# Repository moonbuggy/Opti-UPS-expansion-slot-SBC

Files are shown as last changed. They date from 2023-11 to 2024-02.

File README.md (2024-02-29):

# Opti-UPS Expansion Slot Single Board Computer
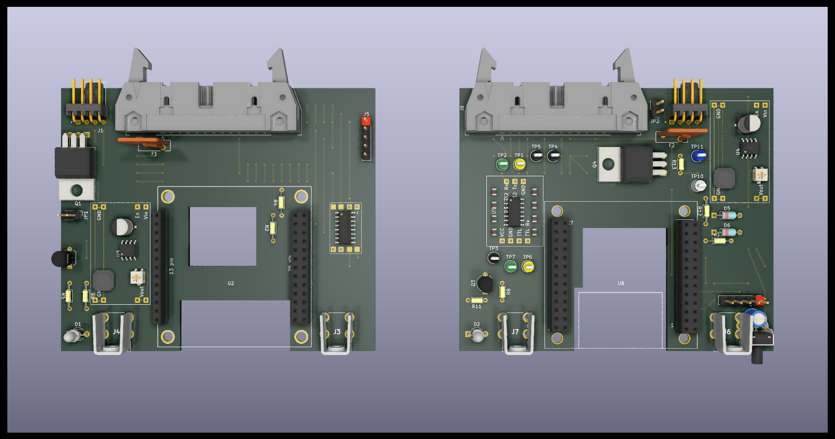
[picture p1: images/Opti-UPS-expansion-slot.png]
3D-render


KiCad files for circuits built on prototyping board that will fit in a UPS
expansion slot, to add an ethernet interface for network UPS management.

*   [Rationale](#rationale)
*   [Single Board Computers](#single-board-computers)
*   [Expansion Boards](#expansion-boards)
    +   [Assembled](#assembled)
    +   [Schematics](#schematics)
    +   [Layouts](#layouts)
    +   [Components](#components)
        -   [Pre-built Modules](#pre-built-modules)
        -   [Mounting](#mounting)
    +   [Status LED](#status-led)
    +   [I²C Header](#i-c-header)
        -   [Real-time Clock](#real-time-clock)
    +   [Fan Connector](#fan-connector)
    +   [Power Cycling](#power-cycling)
*   [Opti-UPS PS1440RM](#opti-ups-ps1440rm)
    +   [Expansion Slot](#expansion-slot)
    +   [Pinouts](#pinouts)
*   [Software](#software)
    +   [NUT](#nut)
        -   [Minimal configuration](#minimal-configuration)
    +   [chrony](#chrony)
    +   [Windows 2000 in Docker](#windows-2000-in-docker)
        -   [/etc/docker/daemon.json](#-etc-docker-daemonjson)
        -   [Dockerfile](#dockerfile)
        -   [docker-compose.yml](#docker-composeyml)
*   [Links](#links)
    +   [Datasheets](#datasheets)

These are designed with an Opti-UPS PS1440RM in mind, but should work in other
UPS expansion slots after adjusting for the pinout of the expansion slot
connection.

There's two different boards, for two different SBCs: an
[Orange Pi Zero](http://www.orangepi.org/orangepiwiki/index.php/Orange_Pi_Zero)
and a [Rock Pi S](https://wiki.radxa.com/RockpiS). There's more information here
about the Rock Pi S version because that's the one I ended up building.

## Rationale
My UPS is 20 years old but still works fine. Except, the official Opti-UPS
software for the UPS won't run in anything newer than Windows 2000 and I don't
want to run a VM on a real computer just to talk to the UPS.

Also, it's just nice to have ethernet coming right out of a UPS, rather than a
serial cable.

Proper expansion cards for the UPS aren't easy to find, due to its age, so
making something to fit seems sensible.

## Single Board Computers
The two SBCs offer different solutions to the problem. The Orange Pi Zero is
cheap and will happily run [Network UPS Tool (NUT)](https://networkupstools.org/).
The Rock Pi S is also relatively cheap, but _should_ be able to run [Windows 2000
in Docker](https://github.com/hectorm/docker-qemu-win2000), allowing the official
Opti-UPS software to run.

The Rock Pi S will want to draw more power than the Orange Pi Zero, and it's
overkill for just running NUT (which it will also happily do), but it is more
capable thus provides more flexibility.

These boards will work directly with other SBCs that have the same pin
arrangement (e.g. Orange Pi Zero 2 and Orange Pi Zero 3), although the spaces
in the boards to fit RJ-45/USB sockets and any CPU heatsinks may need to be
adjusted.

It's not too difficult to customise these boards for other SBCs with different
pin arrangements.

## Expansion Boards
Both boards are fundamentally the same. The main differences are the physical
layout of headers on the SBC they connect to, and the function of each header
pin. It's just a matter of routing tracks appropriately.

The Rock Pi S board does have a [power cycling circuit](#power-cycling) that the
Orange Pi Zero board lacks.

The UPS is connected to _UART2_ (_/dev/ttyS2_) on the Orange Pi Zero and _UART3_
(_/dev/ttyS3_) on the Rock Pi S. There's an overlay in `root/boot/overlay-user/`
to enable the UART on the Rock Pi S.

### Assembled
<p><a href="images/assembled-RockPiS-top.jpg">
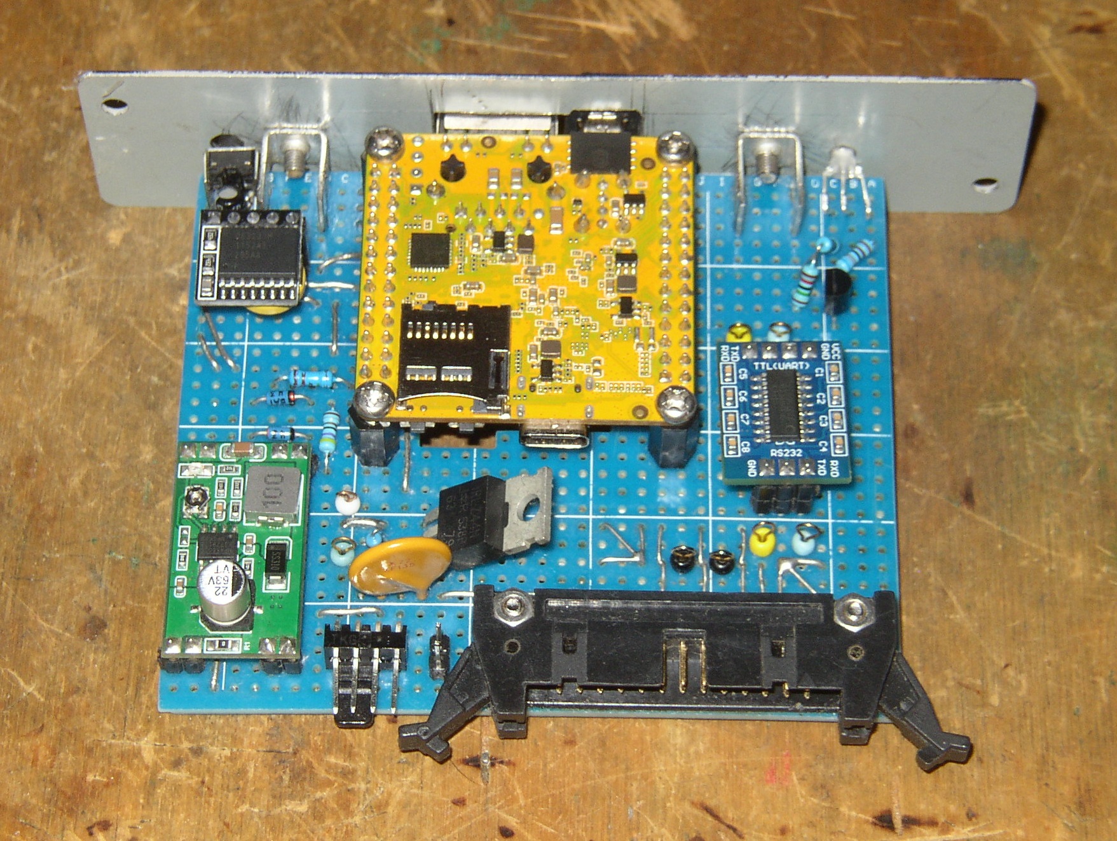
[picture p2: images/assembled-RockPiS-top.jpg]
  
</a><br/>
<em>Rock Pi S board (top)</em></p>

<p><a href="images/assembled-RockPiS-side.jpg">
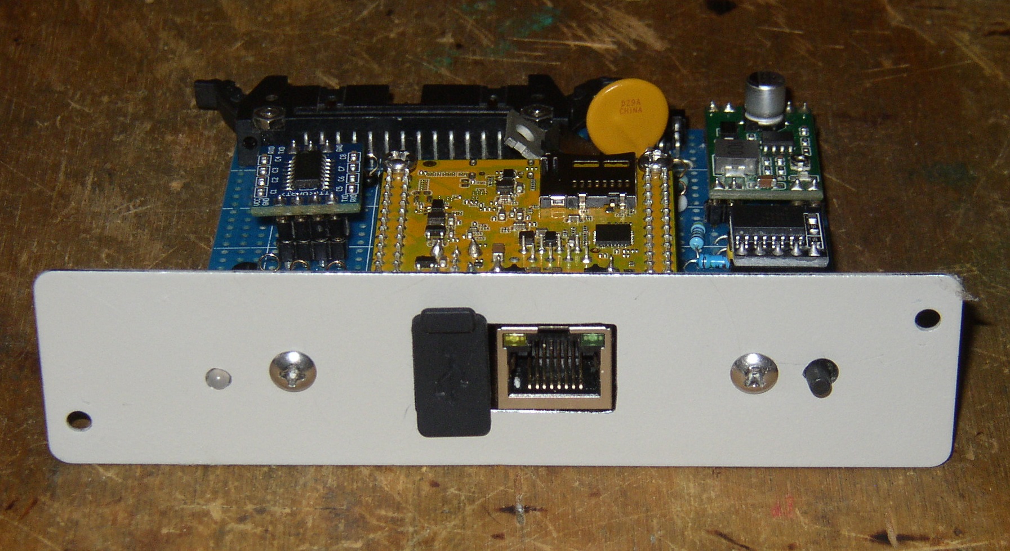
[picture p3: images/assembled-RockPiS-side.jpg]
  
</a><br/>
<em>Rock Pi S board (side)</em></p>

### Schematics
<p><a href="images/schematic-OrangePiZero.png">
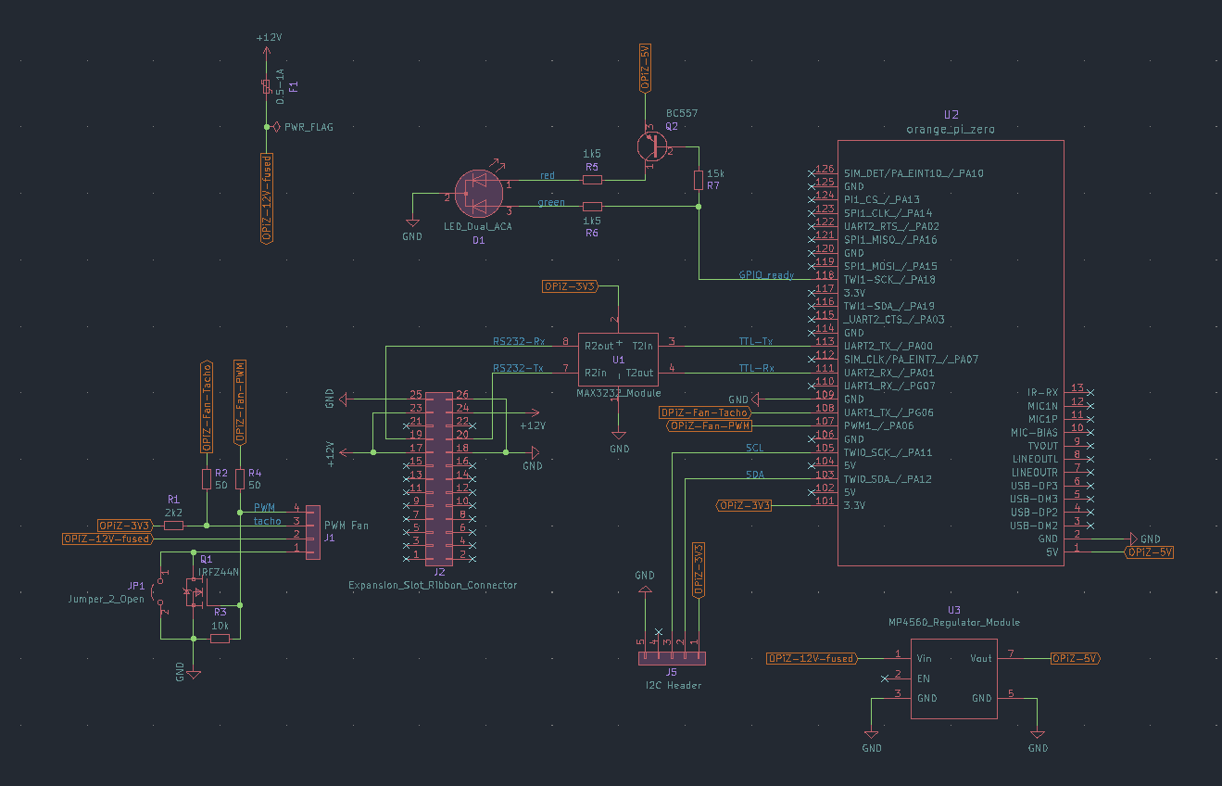
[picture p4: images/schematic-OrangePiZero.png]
  
</a><br/>
<em>Orange Pi Zero schematic</em></p>

<p><a href="images/schematic-RockPiS.png">
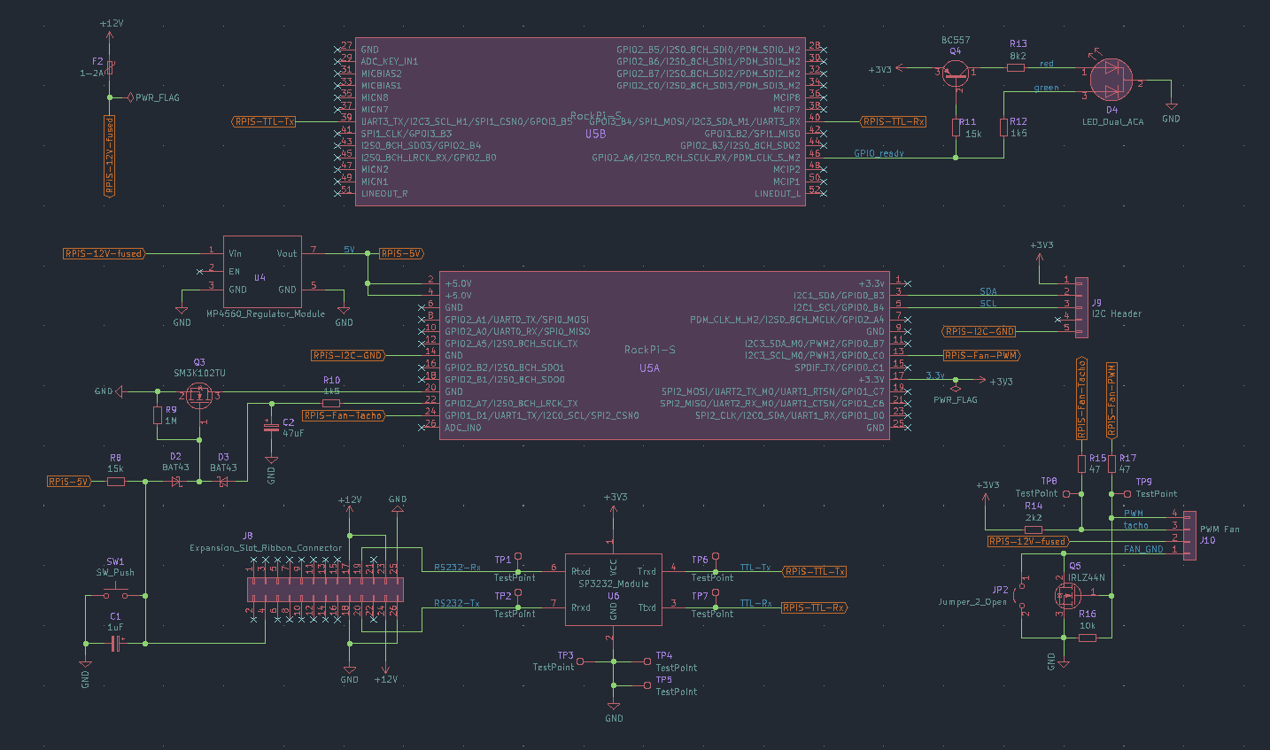
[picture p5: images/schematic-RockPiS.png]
  
</a><br/>
<em>Rock Pi S schematic</em></p>

### Layouts
<p><a href="images/layout-OrangePiZero.png">
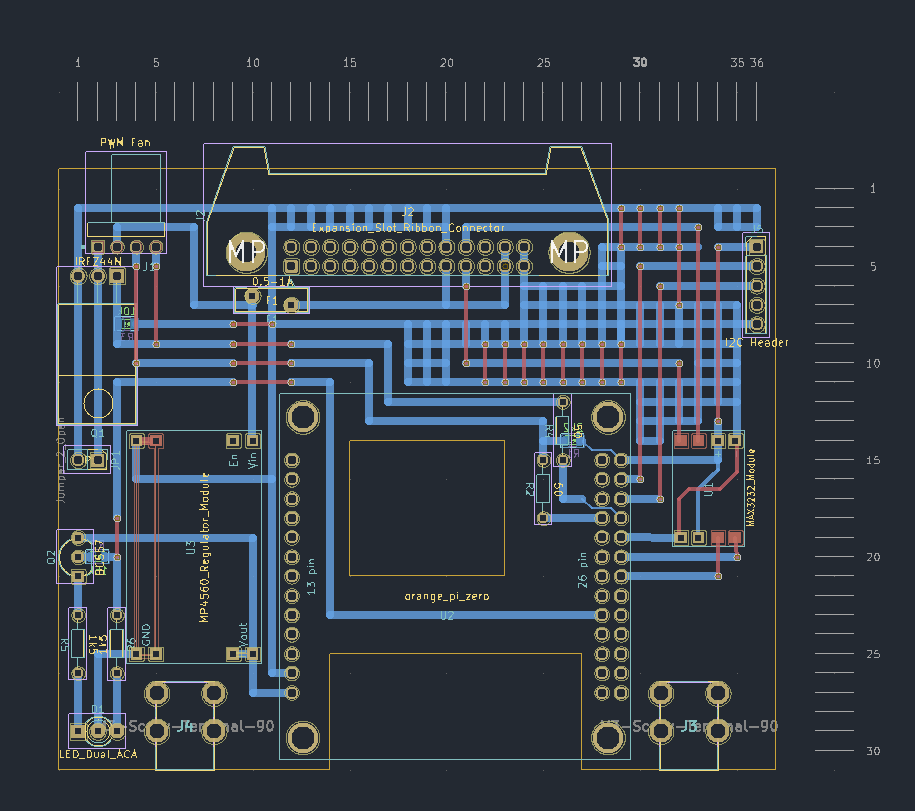
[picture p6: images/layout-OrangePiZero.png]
  
</a><br/>
<em>Orange Pi Zero layout</em></p>

<p><a href="images/layout-RockPiS.png">
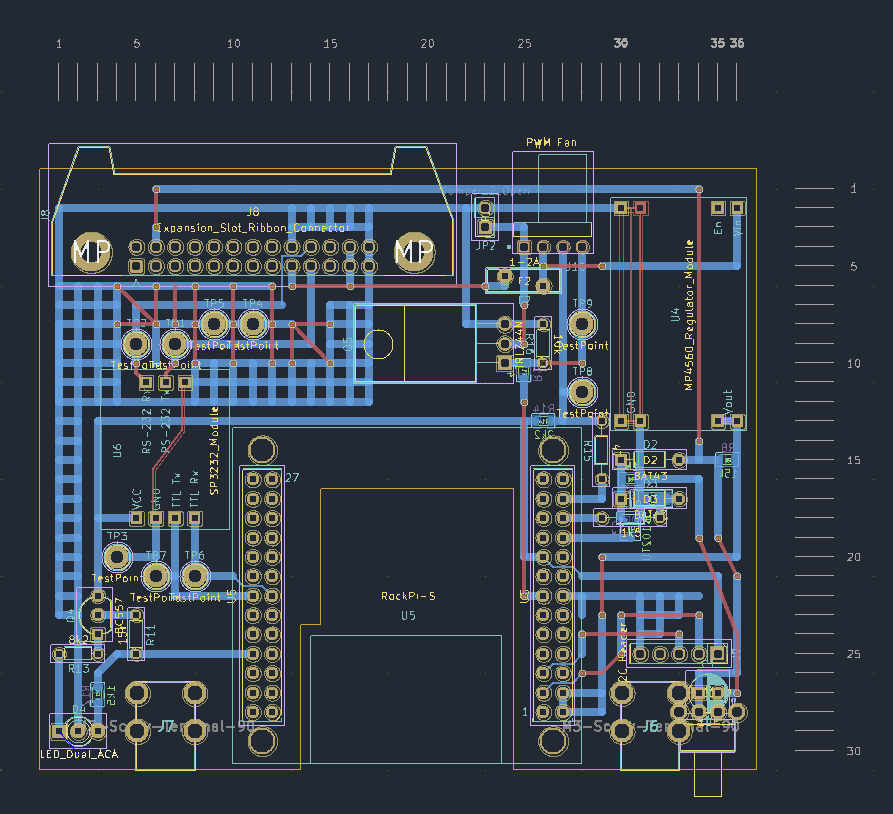
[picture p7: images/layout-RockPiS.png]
  
</a><br/>
<em>Rock Pi S layout</em></p>

The scales around the boards are indicating the number of holes in the PCB,
with a 2.54mm pitch. Thus each increment is equal to 2.54mm.

In most cases, blue tracks should be copper on the bottom of the PCB and red
tracks should be wires on top of the PCB. The thin blue tracks running between
pads on the pin headers will need to be insulated wire.

There's a whole bunch of ground tracks on both PCBs, particularly around the
RS-232 and TTL serial signals, in an attempt to minimise noise in these signals
by guarding their tracks.

The test points on the Rock Pi S board are for convenient diagnostics of the
serial link and the fan's PWM and tachometer signals. They can be omitted.

The modules all have multiple common ground pins, and the MAX3232 module has
multiple common supply pins as well. Any tracks in the layout under/over these
modules connecting these common pins are pre-existing on the modules and don't
need to be created on the PCB.

### Components
#### Pre-built Modules
The power supply and RS-232<->TTL converters on these boards are pre-built
modules, soldered directly to the main board. Suitable modules are cheap on
eBay/AliExpress or from other sources, and they make routing conductors on
prototype board a lot simpler.

There should be room to fit modules of different dimensions than those I've used
without needing to move anything but some conductors. If desired, extending
the length of the board provides ample room to build these modules from scratch
on the board itself.

##### Switching Power Supply - MP4560
<p><a href="images/module-MP4560.jpg">
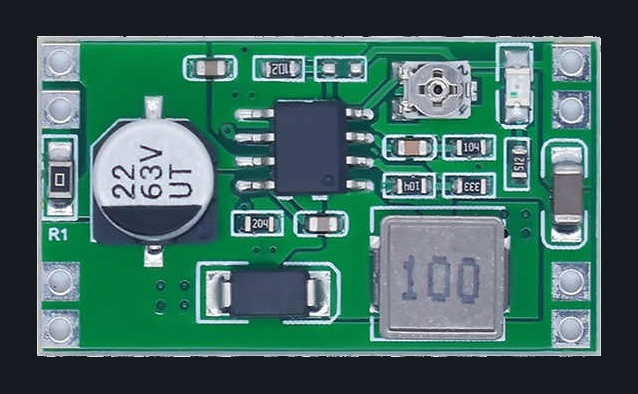
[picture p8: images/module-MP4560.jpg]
  
</a><br/>
<em>MP4560 module</em></p>

We'll be sourcing 12V DC from the UPS expansion slot's connector and regulating
down to 5V for the SBC. An efficient switching supply makes a lot more sense
than a linear regulator, both in terms of heat generation and the current we'll
want to pull through a 28AWG ribbon cable.

The MP4560 seems a good choice because the high switching frequency means the
inductor can be physically smaller than slower options (e.g. LM2596), so there's
not going to be any issue with clearance for a toroid inside the expansion slot.
High switching frequencies should result in less ripple in the output as well.

The module performs well in a load test and shouldn't have any problems meeting
the power demands of the SBCs.
<p><a href="images/module-MP4560-load-test.bmp">
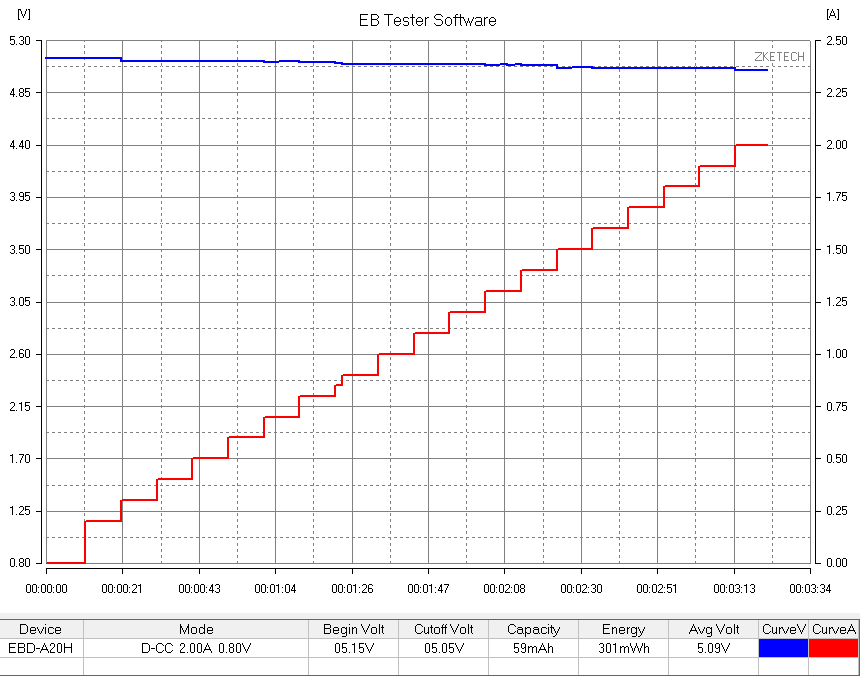
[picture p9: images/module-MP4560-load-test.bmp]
  
</a><br/>
<em>MP4560 module load test</em></p>

##### RS-232 <-> TTL Converter - MAX3232/SP3232
<p><a href="images/module-MAX3232.jpg">
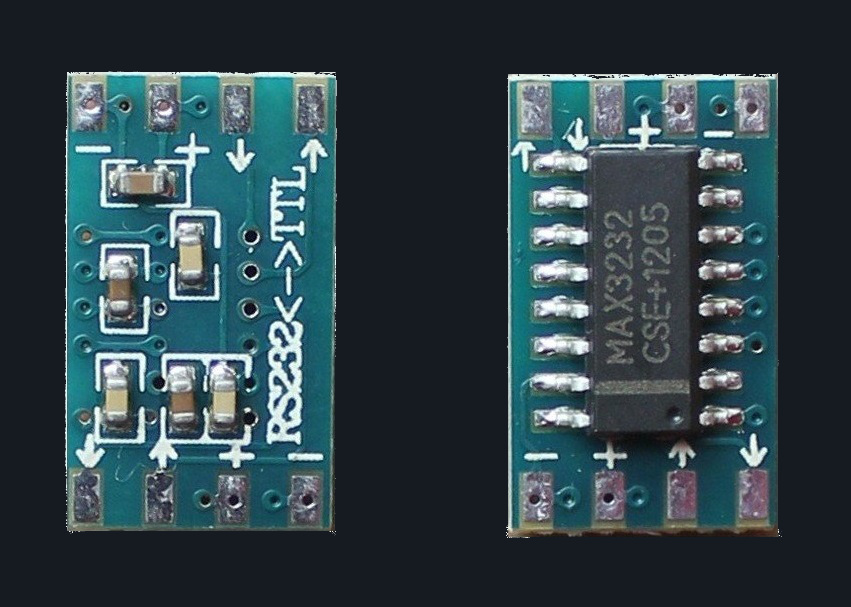
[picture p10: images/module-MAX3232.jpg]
  
</a><br/>
<em>MAX3232 module</em></p>

<p><a href="images/module-SP3232.jpg">
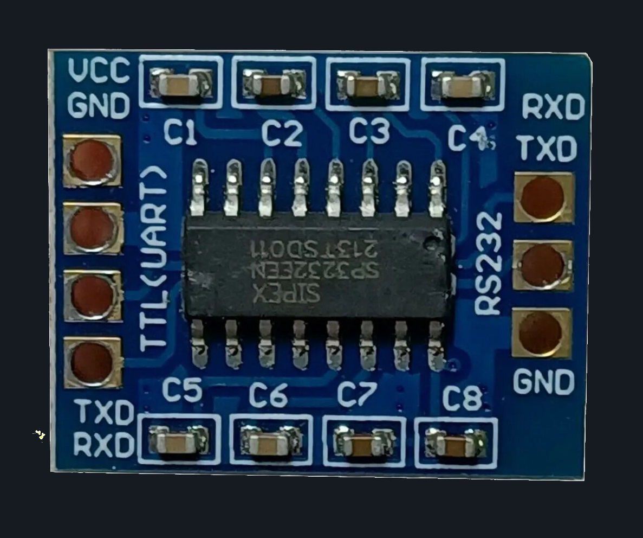
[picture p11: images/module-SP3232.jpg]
  
</a><br/>
<em>SP3232 module</em></p>

The UPS is providing real zero-crossing RS-232, which doesn't do an SBC GPIO any
good, so we need to convert this to the 0-3.3V TTL level the SBC expects. The
MAX3232 seems a good option to do this, however the cheap chips are often
counterfeit and can have issues with noise or lifespan as a result. It could be
worth trying a module using the equivalent SP3232 chip, it may increase the odds
of getting a real chip.

This module sources its 3.3V supply from the SBC's GPIO, so we don't need
another standalone switching supply.

#### Mounting
Right-angled M3 screw terminals are used for mounting the board on the blanking
panel that covers the expansion bay, after cutting appropriate holes for the
RJ-45 socket and the USB port.

<p><a href="images/board-mounting-terminal.jpg">
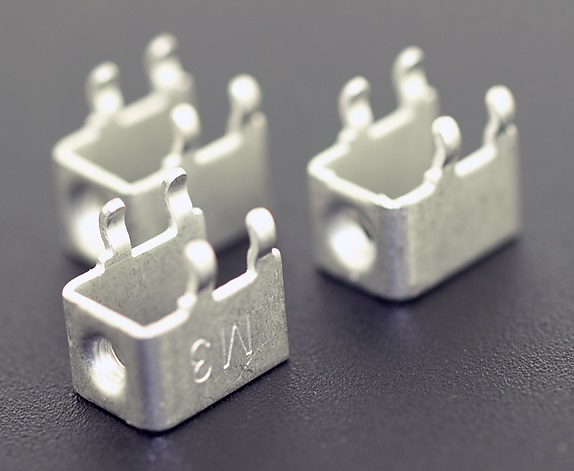
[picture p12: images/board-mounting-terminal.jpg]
  
</a><br/>
<em>Right-angle M3 screw terminal</em></p>

### Status LED
The status LED will be red when the SBC is powered but can be changed to green
via the GPIO. Switching this LED to green when relevant software is loaded
means we have an indication for both 'powered' and 'ready'.

The Orange Pi Zero board uses the 5V supply for the LEDs, and the Rock Pi S
uses the 3.3V supply. This is entirely due to the physical proximity of a supply
rail in each case.

To control the green LED, the Orange Pi Zero board uses pin 118/PA19 (chip 0,
offset 19) and the Rock Pi S boards uses pin 46/GPIO2_A6 (chip 2, offset 6).

If using NUT, the simplest method of control is to create a systemd unit file
for the LED which starts and stops with the _nut_ target. For example,
on the Rock Pi S (note the arguments to _gpioset_ in ExecStart/ExecStop):

##### /etc/systemd/system/ready-led.service
```ini
[Unit]
Description='ready' status indicator LED
After=nut-server.service nut-driver.target
Requires=nut-server.service nut-driver.target
PartOf=nut.target

[Service]
Type=oneshot
ExecStart=gpioset 2 6=1
ExecStop=gpioset 2 6=0
RemainAfterExit=yes

[Install]
WantedBy=nut.target
```

To enable the service:
```sh
sudo systemctl daemon-reload
sudo systemctl enable ready-led
```

Things are a bit more complicated if running Windows 2000 (or NUT) in Docker,
which isn't yet documented here.

To disable the SBC's onboard LEDs (which won't be visible once the board is
installed in the UPS) apply the
[rock-pi-s-disable-leds.dts](root/boot/overlay-user/rock-pi-s-disable-leds.dts)
overlay.

### I²C Header
An I²C connection is made available through jumper pins. This can be used for
any I²C device, but a UPS could be a good place for a real time clock and NTP
server.

#### Real-time Clock
There are many options available, but the easiest is to buy a cheap pre-built
module. The pin header has an appropriate layout for some modules to plug
directly in. For example:

<p><a href="images/module-DS3231.jpg">
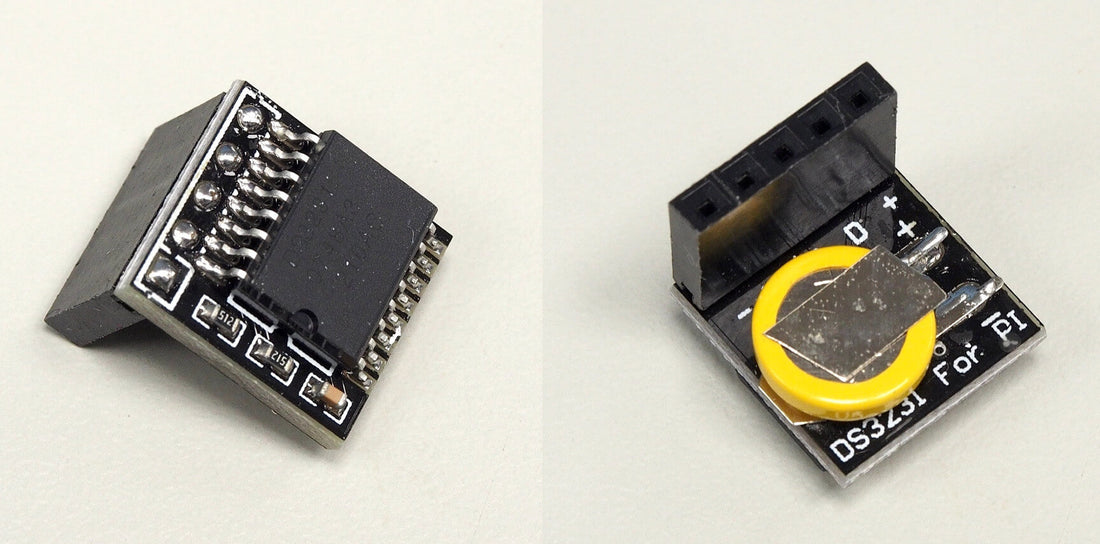
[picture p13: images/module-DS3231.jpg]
  
</a><br/>
<em>DS3231 RTC module</em></p>

The _i2c1_ bus on the Rock Pi S can be enabled with the
[rock-pi-s-i2c1.dts](root/boot/overlay-user/rock-pi-s-i2c1.dts) overlay, and
there's an overlay for a [DS3231N RTC](root/boot/overlay-user/rtc-ds3231n.dts)
as well.

### Fan Connector
The 4-wire fan connector provides the option to power and control a 12V fan from
this board.

For a while the fan in my UPS wasn't spinning. It turned out I'd not attached it
to the right connector in the UPS, but I'd already added the fan connector to
this board, so here it is.

Both the tachometer and RPM signals are 3.3V.

The pull-up resistor on the tachometer signal may not be necessary if we set an
internal pull-up on the SBC, but there's no real harm in doing it in hardware
instead of software.

A 2-wire or 3-wire fan, without a PWM input, can be driven by the MOSFET, if the
nearby jumper is open. If using a 4-wire fan the jumper should be closed,
disabling the MOSFET and letting the PWM signal drive the fan directly.

The IRLZ44N MOSFET is overkill for a fan, but it's easily available and
relatively cheap. Depending on the fan and the duty cycle, a BS170 or something
similar in a TO-92 package could work. An SMD MOSFET, like the SSM3K102TU used
elsewhere on the Rock Pi S board, would also work.

### Power Cycling
The Rock Pi S board will disconnect the SBC from the power when two conditions
are both met:

1.  the UPS signals a loss of mains power by pulling pin 4 on the ribbon cable
    to ground
1.  the SBC signals it has shut down by switching pin 22//GPIO2_A7 (chip 2,
    offset 7) from 3.3V to high impedance

Power will be restored automatically once the UPS indicates mains is restored by
switching ribbon cable pin 4 open circuit, which should in turn cause the SBC to
boot.

The capacitor on the SBC's GPIO signal provides a delay before cutting power
(47uF should be around 30 seconds through the 1M resistor) to ensure ample time
is provided, as the GPIO pin will be pulled low at some midpoint in the shutdown
process rather than at the very end.

We can start a systemd service to indicate we're booting very early in the init
process as such:

##### /etc/systemd/system/booting-signal.service
```ini
[Unit]
Description=boot indication
After=local-fs.target
Requires=local-fs.target
Before=sysinit.target
DefaultDependencies=false

[Service]
Type=oneshot
ExecStart=gpioset -D open-source 2 7=1
ExecStop=gpioset -D open-source 2 7=0
RemainAfterExit=yes

[Install]
WantedBy=sysinit.target
```

To enable the service:
```sh
sudo systemctl daemon-reload
sudo systemctl enable booting-signal
```

The `-D open-source` argument to `gpioset` ensures we don't discharge the
time delay capacitor into the GPIO. Using the default `-D push-pull`
configuration would result in the time delay reducing to less than a second,
effectively disabling the delay in practice.

The push button emulates a loss of mains signals from the UPS and allows us to
cycle the power and restart the SBC if it's been shutdown manually or by some
method that didn't involve a loss of mains power. The button does nothing if the
SBC is signalling it's booted/booting.

## Opti-UPS PS1440RM
### Expansion Slot
The expansion slot has a PCB edge connector in it, connected to a 2x13 pin
socket on the UPS main board via a ribbon cable.

Instead of making a board precise enough to fit into this edge connector, it's
simpler to swap the ribbon cable for one with 2x13 pin connectors on each end,
feed one end through the hole in the expansion slot housing that held the
edge connector, and connect directly to the board.

### Pinouts
The DB9 connector on the UPS is not wired for standard RS-232:
<p><a href="images/Opti-UPS-DB9-connector.png">
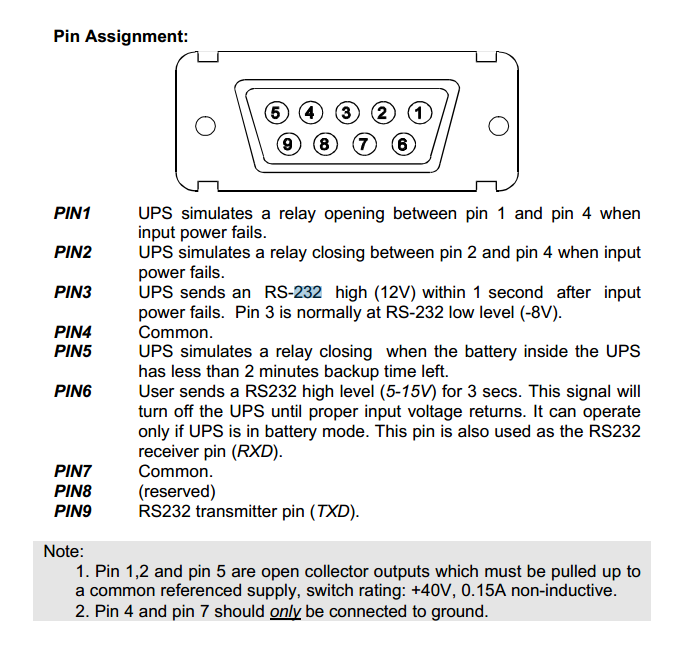
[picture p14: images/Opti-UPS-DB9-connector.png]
  
</a><br/>
<em>Opti-UPS PS1440RM DB9 connector pinout</em></p>

The cable that comes with the UPS switches wires around so that the other end
of it is wired in the standard way for RS-232. There appear to be diodes present
as well.

Some of the pins in the expansion slot connector are common with those in the
DB9 connector, so we have an easy way to find the data pins in the expansion
slot.

Probing the 2x13 header with a multimeter and component tester (via a long
ribbon cable, so as not to work inside a live UPS) makes the 12V DC supply pins
apparent.

<p><a href="images/schematic-cable.png">
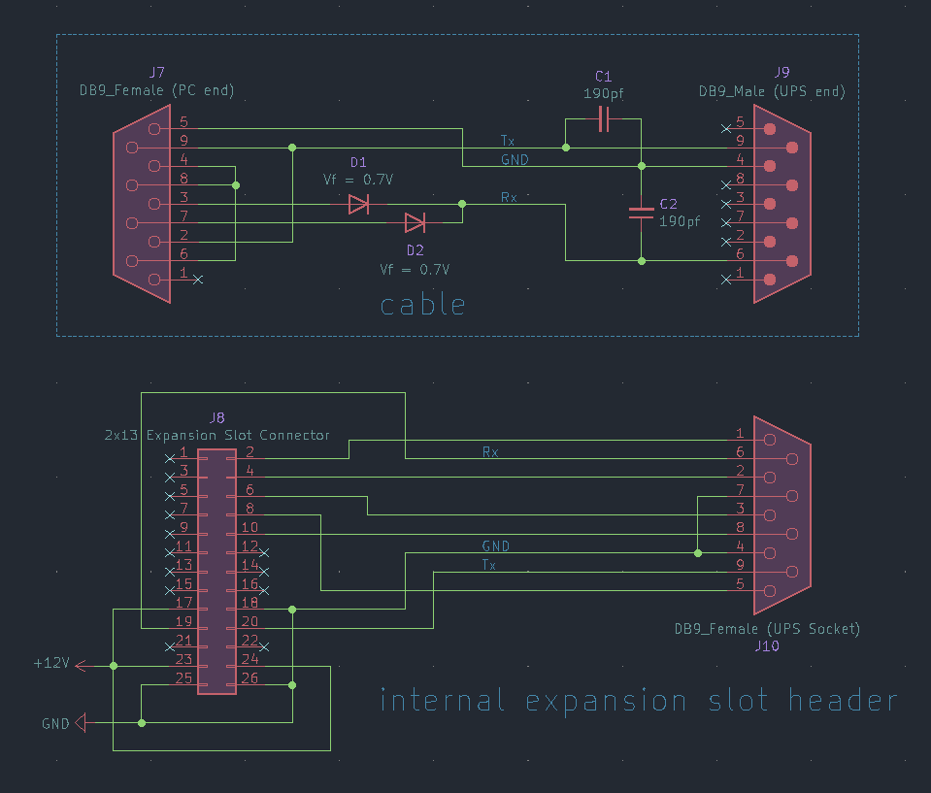
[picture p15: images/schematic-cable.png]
  
</a><br/>
<em>PS1440RM cable and header pinouts</em></p>

## Software
### NUT
It may be necessary to manually add the _nut_ user to the _dialout_ and/or _tty_
groups, so it has permissions for the serial device:

```sh
sudo usermod -a -G dialout nut
sudo usermod -a -G tty nut
```

The _uart3_ interface on the Rock Pi S can be enabled with the
[rock-pi-s-uart3.dts](root/boot/overlay-user/rock-pi-s-uart3.dts) overlay.

#### Minimal configuration
##### /etc/nut/ups.conf
```ini
[ps1440rm]
  driver = optiups
  port = /dev/ttyS3
  desc = "Opti-UPS PS-1440RM"
```

##### /etc/nut/upsd.conf
```sh
# listen to all IPv4
LISTEN 0.0.0.0 3493
```

#### /etc/nut/nut.conf
```conf
# enable remote connections
MODE=standalone
```

##### /etc/nut/upsd.users
```sh
[upsmon]
  password = password
  upsmon primary
```

##### /etc/nut/upsmon.conf
Setting `powervalue` to zero means we're just monitoring, this device won't be
shut down when power fails. `MINSUPPLIES` needs to be zero to allow this.

```sh
MONITOR ps1440rm@localhost 0 upsmon password primary
MINSUPPLIES 0
```

This configuration is not suitable for production.

It's important to shut the SBC down once battery levels are low, because we
don't know whether the UPS will cut the 12V supply we're using to protect the
batteries from over-discharge. In the case of the Rock Pi S board, the SBC will
automatically start again once mains power is restored. See
[Power Cycling](#power-cycling).

##### /etc/systemd/system/nut-server.service.d/override.conf
```ini
[Unit]
# Sometimes nut-server can fail to start at boot due to the network not being up
Wants=nut-driver.target network-online.target
Requires=network.target network-online.target
```

### chrony
The default configuration for the RTC is for chrony to tell the system to set it
every 11 minutes. To let chrony set the time from the RTC (as a backup if
there's some issue with the GPS), it needs to be run with the -s argument.

##### /etc/default/chrony
```sh
# This is a configuration file for /etc/init.d/chrony and
# /lib/systemd/system/chrony.service; it allows you to pass various options to
# the chrony daemon without editing the init script or service file.

# Options to pass to chrony.
DAEMON_OPTS="-F 1 -r -m -s"
```

### Windows 2000 in Docker
> [!NOTE]
> This is still a work in progress and is not complete. The official software
> doesn't necessarily offer any advantage over running NUT and this may be a waste
> of time and effort.
>
> The Docker container runs okay, but is somewhat sluggish. The Opti-UPS software
> installs and runs. However, as it stands at the moment, the COM port isn't
> functioning inside Windows 2000. This presents as a driver issue, but I assume
> the root cause is me misunderstanding the QEMU configuration,.

We can start with the [hectorm/qemu-win2000](https://hub.docker.com/r/hectorm/qemu-win2000)
Docker image and install the official Opti-UPS software to monitor things.

This will require an SD card installed into the Rock Pi S, as there's not enough
room on the 4GB eMMC for the OS and the image. To move the Docker data files to
the SD card (after it has been formatted and mounted):

#### /etc/docker/daemon.json
```json
{
        "data-root": "/mnt/sdcard/docker/"
}
```

The image requires _qemu-kvm_:
```sh
sudo apt-get install --no-install-recommends qemu-kvm
```

#### Dockerfile
It looks like we need to modify the image to tell QEMU the serial port exists.
We're using UART3 which will be _/dev/ttyS3_ in Armbian and made available as
the same in the Docker container.

QEMU, running inside the container, can be pointed in the right direction as
such:
```Dockerfile
FROM "hectorm/qemu-win2000:latest-arm64v8"

ENV VM_SERIAL_DEVICE="ttyS3"

RUN awk '!f && sub(/if/, "set -- \"$@\" -chardev serial,path=\"/dev/${VM_SERIAL_DEVICE:-ttyS3}\",id=hostserial\nset -- \"$@\" -device pci-serial,chardev=hostserial\n\nif"){f=1} 1' \
        /etc/runit/runsvdir/default/qemu/run > ./run.temp \
  && cat ./run.temp > /etc/runit/runsvdir/default/qemu/run \
  && rm -f ./run.temp
```

Build with: `docker build -t moonbuggy2000/qemu-win2000-opti-ups:latest-arm64v8 .`

> [!WARNING]
> This doesn't work. The port appears but Windows 2000 doesn't find suitable
> drivers for it. Using `isa-serial` instead of `pci-serial` leads to the driver
> installing automatically and apparently without complaint, but it doesn't seem
> to be getting data from the UPS in that case either.

#### docker-compose.yml
We don't have a huge amount of RAM to play with, and things slow to a crawl if
we're heavily using the zram, so we'll need to limit the RAM the container can
use.

```yaml
version: '3.9'

services:
  opti-ups:
    image: moonbuggy2000/qemu-win2000-opti-ups:latest-arm64v8
    container_name: opti-ups
    hostname: opti-ups
    restart: unless-stopped
    ports:
      - 3389:3389/tcp
      - 5900:5900/tcp
      - 6080:6080/tcp
    devices:
      - "/dev/kvm:/dev/kvm"
      - "/dev/ttyS3:/dev/ttyS3"
    environment:
      - "VM_CPU=3"
      - "VM_KVM=1"
      - "VM_RAM=128M"
      - "VM_SERIAL_DEVICE=ttyS3"
    volumes:
      - "opti-ups:/mnt"
    network_mode: bridge

volumes:
  opti-ups:
    driver: local
    name: opti-ups
```

## Links
### Datasheets
*   [BS170](https://www.onsemi.com/pdf/datasheet/mmbf170-d.pdf)
*   [DS3231](https://www.analog.com/media/en/technical-documentation/data-sheets/DS3231.pdf)
*   [IRLZ44N](https://www.infineon.com/dgdl/Infineon-IRLZ44N-DataSheet-v01_01-EN.pdf?fileId=5546d462533600a40153567217c32725)
*   [MAX3232](https://www.analog.com/media/en/technical-documentation/data-sheets/MAX3222-MAX3241.pdf)
*   [MP4560](https://www.monolithicpower.com/en/documentview/productdocument/index/version/2/document_type/Datasheet/lang/en/sku/MP4560/document_id/305)
*   [SP3232](https://assets.maxlinear.com/web/documents/sipex/datasheets/sp3222e_sp3232e.pdf)
*   [SSM3K102TU](https://au.mouser.com/datasheet/2/408/21598-27399.pdf)

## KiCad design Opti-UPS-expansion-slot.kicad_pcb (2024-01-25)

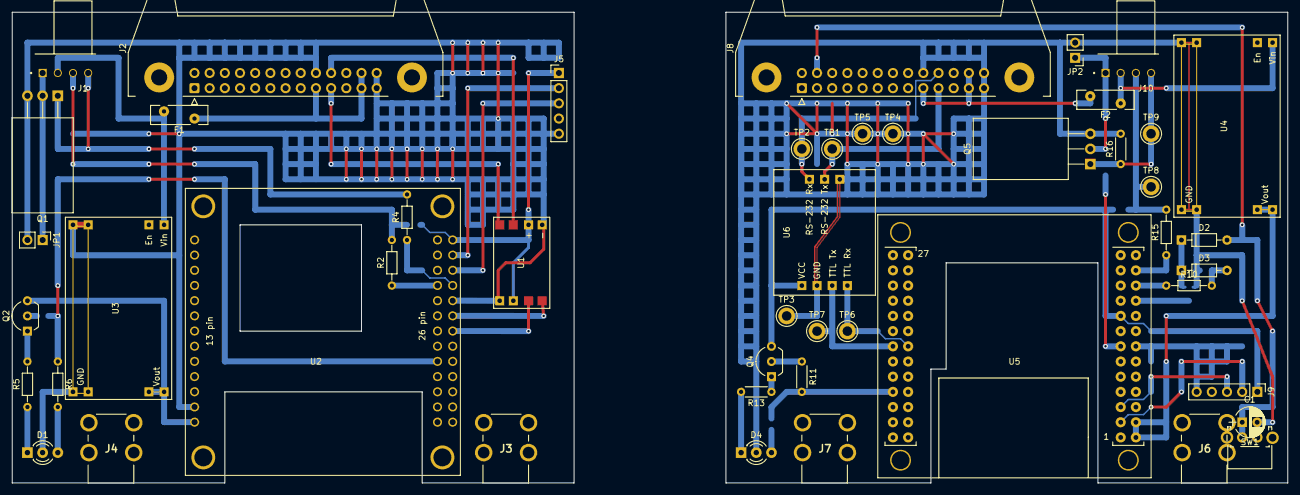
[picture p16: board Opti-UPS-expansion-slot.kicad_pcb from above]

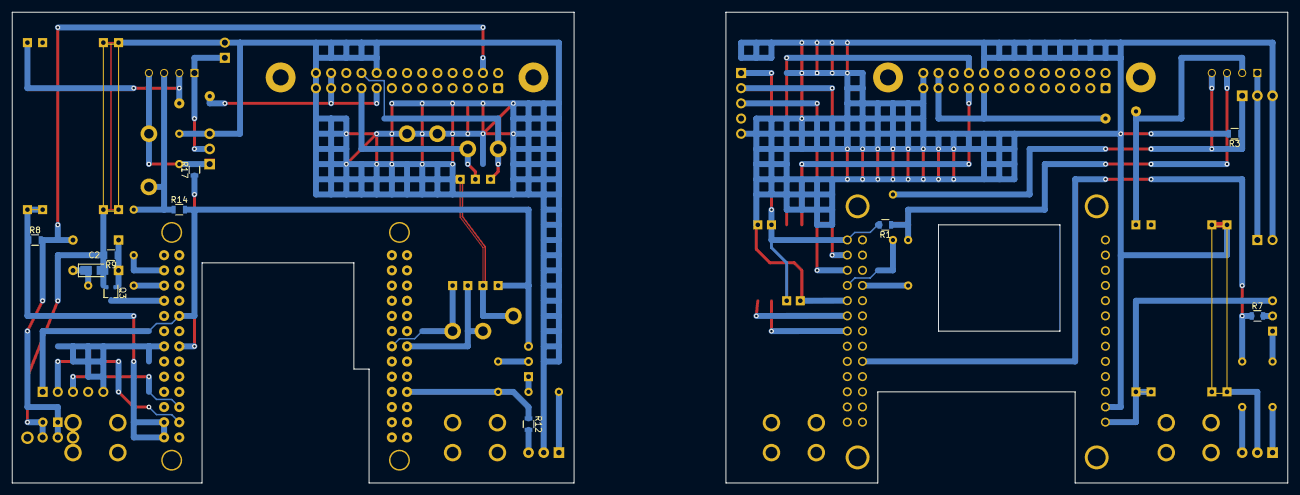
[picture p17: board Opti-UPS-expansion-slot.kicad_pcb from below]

Board: 2 copper layers, 213.4 x 78.7 mm, 58 parts (10 on the bottom side), 46 nets.

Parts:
C1: 1uF; CP_Radial_D5.0mm_P2.50mm
C2: 47uF; CP_Tantalum_Case-A_EIA-3216-18_Reflow
D1, D4: LED_Dual_ACA; LED_D3.0mm-3
D2, D3: BAT43; D_DO-35_SOD27_P7.62mm_Horizontal
F1: 0.5-1A; Fuse_Bourns_MF-RHT200
F2: 1-2A; Fuse_Bourns_MF-RHT200
J1, J10: PWM Fan; Fan_Pin_Header_4Pin_Horizontal
J2, J8: Expansion_Slot_Ribbon_Connector; IDC-Header_2x13-1MP_P2.54mm_Latch_Horizontal
J3, J4, J6, J7: M3-Screw-Terminal-90
J5, J9: I2C Header; Pin_Header_Straight_1x05_Pitch2.54mm
JP1, JP2: Jumper_2_Open; Pin_Header_Straight_1x02_Pitch2.54mm
Q1: IRFZ44N; TO-220-3_Horizontal
Q2, Q4: BC557; TO-92_Inline_Wide
Q3: SM3K102TU; SOT-323_SC-70
Q5: IRLZ44N; TO-220-3_Horizontal
R1, R14: 2k2; R_0805
R2, R4: 50; R_Axial_DIN0204_L3.6mm_D1.6mm_P7.62mm_Horizontal
R3: 10k; R_0805
R5, R6, R10: 1k5; R_Axial_DIN0204_L3.6mm_D1.6mm_P7.62mm_Horizontal
R7, R8: 15k; R_0805
R9: 1M; R_0805
R11: 15k; R_Axial_DIN0204_L3.6mm_D1.6mm_P5.08mm_Horizontal
R12: 1k5; R_0805
R13: 8k2; R_Axial_DIN0204_L3.6mm_D1.6mm_P5.08mm_Horizontal
R15: 47; R_Axial_DIN0204_L3.6mm_D1.6mm_P7.62mm_Horizontal
R16: 10k; R_Axial_DIN0204_L3.6mm_D1.6mm_P5.08mm_Horizontal
R17: 47; R_0805
SW1: SW_Push; SW_Tactile_SPST_Angled_PTS645Vx83-2LFS
TP1, TP7: TestPoint; Test_Point_Keystone_Yellow
TP2, TP6: TestPoint; Test_Point_Keystone_Green
TP3, TP4, TP5: TestPoint; Test_Point_Keystone_Black
TP8: TestPoint; Test_Point_Keystone_White
TP9: TestPoint; Test_Point_Keystone_Blue
U1: MAX3232_Module
U2: orange_pi_zero; orangepi-zero-headers-no-debug
U3, U4: MP4560_Regulator_Module
U5: RockPi-S; RockPi-S-pads-only
U6: SP3232_Module; SP3232_Module_1CH

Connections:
+3V3: J9.1, Q4.3, R14.2, U5.17, U6.1
+12V: F1.1, F2.2, J2.17, J2.23, J2.24, J8.17, J8.23, J8.24
/Orange Pi Zero/GPIO_ready: R6.1, R7.1, U2.118
/Orange Pi Zero/PWM: J1.4, Q1.1, R3.1, R4.2
/Orange Pi Zero/RS232-Rx: J2.19, U1.8
/Orange Pi Zero/RS232-Tx: J2.20, U1.7
/Orange Pi Zero/SCL: J5.3, U2.105
/Orange Pi Zero/SDA: J5.2, U2.103
/Orange Pi Zero/TTL-Rx: U1.4, U2.111
/Orange Pi Zero/TTL-Tx: U1.3, U2.113
/Orange Pi Zero/green: D1.3, R6.2
/Orange Pi Zero/red: D1.1, R5.1
/Orange Pi Zero/tacho: J1.3, R1.1, R2.2
/Rock Pi S/FAN_GND: J10.1, JP2.1, Q5.2
/Rock Pi S/GPIO_ready: R11.2, R12.1, U5.46
/Rock Pi S/PWM: J10.4, Q5.1, R16.1, R17.2, TP9.1
/Rock Pi S/RS232-Rx: J8.19, TP1.1, U6.6
/Rock Pi S/RS232-Tx: J8.20, TP2.1, U6.7
/Rock Pi S/SCL: J9.3, U5.5
/Rock Pi S/SDA: J9.2, U5.3
/Rock Pi S/green: D4.3, R12.2
/Rock Pi S/red: D4.1, R13.2
/Rock Pi S/tacho: J10.3, R14.1, R15.2, TP8.1
GND: C1.2, C2.2, D1.2, D4.2, J2.18, J2.25, J2.26, J5.5, J8.18, J8.25, J8.26, JP1.2, JP2.2, Q1.3, Q3.2, Q5.3, R3.2, R9.2, R16.2, SW1.1, TP3.1, TP4.1, TP5.1, U1.1, U1.5, U2.2, U2.109, U3.3, U3.4, U3.5, U3.6, U4.3, U4.4, U4.5, U4.6, U6.2, U6.5
unnamed: C1.1, D2.2, J8.4, R8.2, SW1.2
unnamed: C2.1, D3.2, R10.2
unnamed: D2.1, D3.1, Q3.1, R9.1
unnamed: J1.1, JP1.1, Q1.2
unnamed: Q2.1, R5.2
unnamed: Q2.2, R7.2
unnamed: Q3.3, U5.20
unnamed: Q4.1, R13.1
unnamed: Q4.2, R11.1
unnamed: R10.1, U5.22
OPiZ-3V3: J5.1, R1.2, U1.2, U1.6, U2.101
OPiZ-5V: Q2.3, U2.1, U3.7, U3.8
OPiZ-12V-fused: F1.2, J1.2, U3.1
OPiZ-Fan-PWM: R4.1, U2.107
OPiZ-Fan-Tacho: R2.1, U2.108
RPiS-5V: R8.1, U4.7, U4.8, U5.2, U5.4
RPiS-12V-fused: F2.1, J10.2, U4.1
RPiS-Fan-PWM: R17.1, U5.13
RPiS-Fan-Tacho: R15.1, U5.24
RPiS-I2C-GND: J9.5, U5.14
RPiS-TTL-Rx: TP7.1, U5.40, U6.3
RPiS-TTL-Tx: TP6.1, U5.39, U6.4
